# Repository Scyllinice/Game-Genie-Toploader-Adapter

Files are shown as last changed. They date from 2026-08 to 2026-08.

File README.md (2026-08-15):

# Game Genie Toploader Adapter

<p xmlns:cc="http://creativecommons.org/ns#" >This work by <span property="cc:attributionName">Scyllinice</span> is licensed under <a href="https://creativecommons.org/licenses/by-nc/4.0/?ref=chooser-v1" target="_blank" rel="license noopener noreferrer" style="display:inline-block;">Creative Commons Attribution-NonCommercial 4.0 International</a></p>



<a href="https://www.pcbway.com/project/shareproject/Game_Genie_Toploader_Adapter_25efb8dd.html">PCB from PCBWay</a>

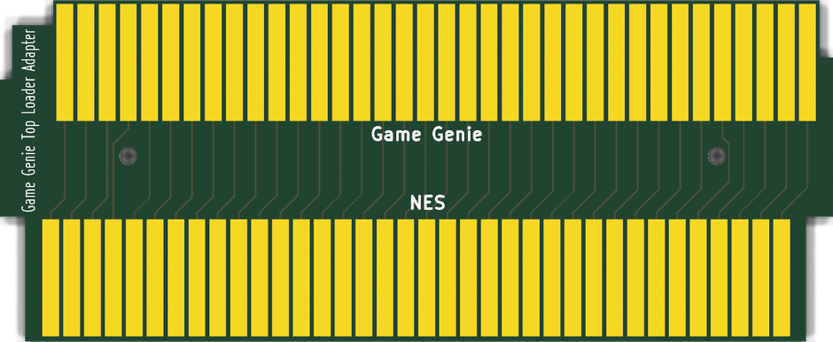
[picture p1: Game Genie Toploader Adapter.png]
Render


This is a adapter/riser PCB for using an original Game Genie on your top loading NES. It also works for clone NES systems that load directly from the cart instead of using emulation (a Retron 5, for example, will not work).

The only component needed to build this PCB into a functioning unit would be a 2.54mm pitch 2x36 pin (72 pin total) edge connector. You can search **5530843-8** for a part number as well.

I have had success using the following edge connectors:

* [Edge connector 1](https://www.aliexpress.us/item/3256802817047324.html)
* [Edge connector 2](https://www.aliexpress.us/item/2251832843397196.html)
* [DigiKey](https://www.digikey.com/en/products/detail/te-connectivity-amp-connectors/5530843-8/770547)

When soldering the edge connector to the top of the board, you will need to bend in the pins a bit as the board is only 1.2mm thick to match the original thickness of a NES retail cartridge. This helps preserve the NES cartridge connector. 

For longevity, it is recommended to use an ENIG finish with gold fingers. HASL (or Lead Free HASL) will still work, but it's more fragile and can fail over time.

[JLCPCB](https://jlcpcb.com/) is generally better priced for ENIG gold fingers than PCBWay. As the time of this writing, you can get 5 of these boards for about $20 US at JLCPCB.

## 3D printed enclosure — [`mech/`](mech/README.md)

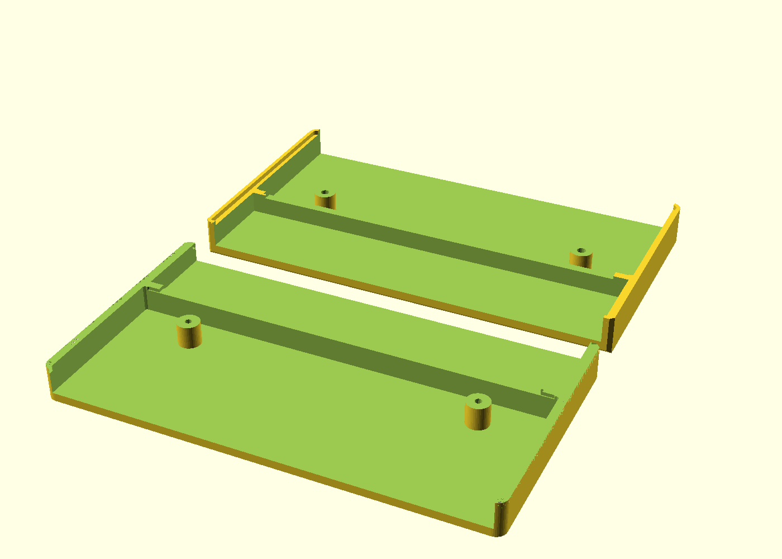
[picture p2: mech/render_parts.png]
both halves, laid out as they print


A two-part shell, **106.1 × 16.8 × 58.4 mm**, held together by two M2 screws through
the board's own mounting holes. Prints without supports; `mech/front.stl` and
`mech/back.stl` are ready to slice.

## The KiCad project lives in [`pcb/`](pcb/README.md)

The board is now **generated from source rather than drawn**: a 72-pin pinout table and
a set of measured dimensions, from which the footprints, symbols, schematic, board,
copper and fab outputs are all produced by `make rebuild`.

```
cd pcb
make            check what is committed — DRC, ERC, card-edge rules, and the
                comparison against the board that was released
make rebuild    regenerate everything from the two source tables
make fab        gerbers, drill, position file, BOM
```

Regenerating wants the pinned toolchain — `./dc bash -c "cd pcb && make rebuild"` runs
it in a container with KiCad 10 and OpenSCAD, which is what the committed files were
built with. See [`.devcontainer/`](.devcontainer/README.md). Checking works with
whatever KiCad you have.

It is the same board. The hand-drawn files this project shipped with are frozen in
[`pcb/reference/`](pcb/reference/README.md), and every run subtracts the generated
board from them — 144 pads, 72 nets, 14 outline corners, both holes, all three silk
texts, to within 1 µm. Nothing about the physical board, the pinout or the fab package
has changed.

What the rebuild adds: a schematic that passes ERC (the drawn one reports 54 direction
conflicts, because one symbol was used for both ends of a pass-through), card-edge
checks KiCad's DRC does not have (finger pitch, front/back registration, the bevel
zone, the contact wipe path), ENIG and the 1.2 mm stackup declared in the gerber job
file rather than only in this README, and a rebuild that is byte-identical run to run.

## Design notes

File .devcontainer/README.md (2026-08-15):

# Dev container — the pinned toolchain

Everything in this repository is generated, so the versions of the tools that generate
it are part of the design. This pins them.

```
./dc bash -c "cd pcb && make rebuild"     regenerate the board
./dc bash -c "cd mech && make"            regenerate the STLs
./dc                                      interactive shell
./dc --build                              rebuild the image
```

Or open the folder in VS Code and reopen in the container.

## What's inside

| tool | version | used by |
|---|---|---|
| **KiCad** (`kicad-cli` + `pcbnew` python + libraries) | 10.0.x | everything in `pcb/` |
| **OpenSCAD** (+ xvfb for PNG export) | 2021.01 | `mech/` |
| **Pillow** | distro | `pcb/gen_render.py`, which crops renders on the alpha channel |

Base is `ubuntu:24.04` with KiCad from the official PPA — `kicad-cli` and the `pcbnew`
module come from the same package, so they cannot drift apart. About 4 GB built, most
of which is `kicad-packages3d`; that is not optional, because without it every
`kicad-cli pcb render` draws a bare board and the README image comes out of that
renderer.

## Why KiCad 10 when the host has 9

**To match the desktop install.** The generators themselves do not care — the whole
`pcb/` pipeline runs unchanged on 9.0.8 and 10.0.5 and produces a board that passes
`compare_original.py` either way, verified both ways. What differs is the file they
write: 2465 lines of schema between them, none of it geometry. So regenerating on the
wrong version rewrites the committed board without changing it, and the next real
change would be invisible inside that diff.

It matters in the other direction too, and this one has actually happened: keep the
headless toolchain on 9.x, open the board once in a KiCad 10 desktop, and the desktop
upgrades the file in place — after which 9's `pcbnew` cannot load it at all
(`LoadBoard` returns `None`).

`pcb/check_toolchain.py` prints which KiCad is about to run and warns if it is not
10.x. It warns rather than fails: checking a board on whatever you have is reasonable,
and `make drc` on 9.x is perfectly valid. It is *regenerating* that costs you a diff.

## Why it is this small

A PCB toolchain will happily grow to tens of gigabytes — vendor FPGA suites, firmware
SDKs, simulators, autorouters. None of that applies to a board with no active
components on it, so none of it is here. The one omission that is a design decision
rather than a size decision is the autorouter: `pcb/route.py` solves all 72 conductors
in closed form and audits every segment before writing, and an autorouted board is a
different shape every run and cannot be reviewed as a diff.

## Not in here

Interactive GUIs: the KiCad editor and the OpenSCAD preview. Run those on the host.

## Notes

`dc` passes `--user $(id -u):$(id -g)` so files created on the bind mount stay yours,
and `PYTHONDONTWRITEBYTECODE=1` because a `.pyc` written by the container is validated
against a source mtime written by the host, and those are not the same clock. Measured
on an earlier project: an edited pin table kept importing its previous definitions from
a cached `.pyc`. Editing `pcb/lib/pinout.py`, regenerating, and getting the old nets on
a board that passes every check is the exact failure that costs a board.

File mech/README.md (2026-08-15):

# mech/ — the printed shell

A two-part enclosure for the adapter. The console end is built like a real
cartridge's — the shell carries on past the gold fingers as a skirt and the fingers
sit recessed inside a **mouth** that the console's 72-pin connector rises into. The
top is open so the Game Genie plugs straight into the edge connector.

both halves, laid out as they print

**106.1 × 16.8 × 58.4 mm** — the width and thickness are a real cartridge's. Two M2
screws. No supports, no glue, nothing else printed.

```
make            front.stl + back.stl
make gauge      the fit gauge — PRINT THIS FIRST
make render     the five PNGs in this directory
make params     re-export board.scad after a change to the PCB
```

## The console end

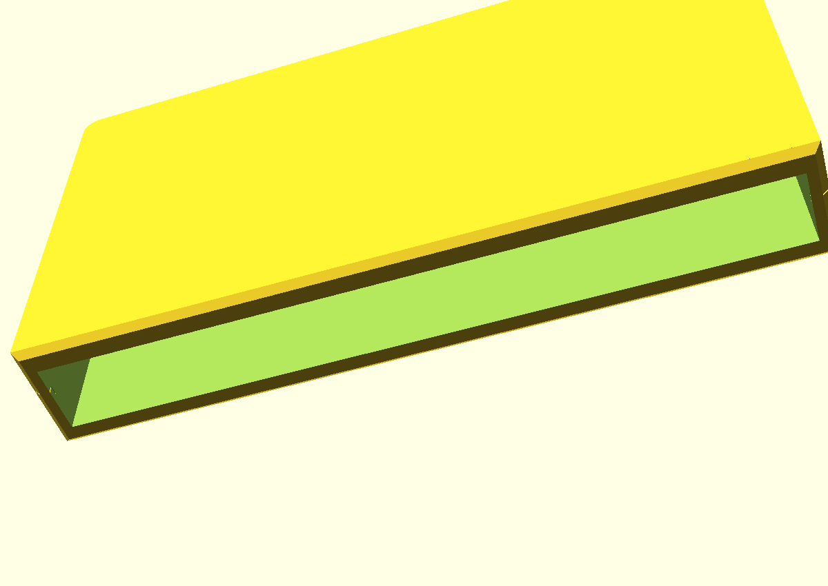
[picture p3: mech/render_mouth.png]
the mouth, from below


Those measurements were taken against a front loader, which does not weaken them
here: the top loader and the front loader take the same 72-pin connector and the same
cartridge, by design. One cart fits both, so a cart's mouth clears both connectors —
and everything in this table is a dimension *of the cartridge*, not of a console.
Console-shell features (tray posts, guide ribs, clamp pads) would not transfer, and
none of them are in this model.

| | | |
|---|---|---|
| skirt | fingers recess **7 mm** up inside the mouth | caliper on a real cart: 7.08; interference-scanning a cart through an assembled shell bounds it to 6.64–7.02 |
| mouth | **101.3 × 10.4 mm** opening | sized for the console's connector **body** (~100 × 10 mm), not for the fingers — the body is what rises into the pocket |
| lips | **3.4 mm** back face, **3.0 mm** label face | what is left of the 16.8 mm thickness either side of the mouth |
| open depth | **19.7 mm** from the bottom face | leaves **12.7 mm** of card for the connector to reach, which is exactly what a real cart leaves |
| bulkhead | closes the cavity above the mouth | the card edge seats on it; a real cart uses 1.4 mm per half, this is 2.2 mm |
| chamfer | **1 mm** at 45° round the bottom face | the lead-in; without it the shell catches on its own square edge |
| outer | **106.1 mm** wide, **16.8 mm** thick | a cart's connector-end width and its full thickness |

A guess of 1 mm for that recess failed a dry fit once, which is why it is a measured
number and not a plausible one.

## Before you print

**The board and the console end are measured. The Game Genie's edge connector is
not.** It is a bought part nobody here has calipered, and the defaults in
`enclosure.scad` are a plausible 95 × 11 × 12 mm — check yours and correct them:

| parameter | what to measure |
|---|---|
| `CONN_L` | body length, along the board |
| `CONN_D` | body depth, across the board — **this sets how thick the whole shell is** |
| `CONN_H` | body height above the board's top edge |
| `CONN_OVERLAP` | how far the body reaches down past that edge, if at all |

Then **print the fit gauge**. It is the bottom 33 mm of both halves — the mouth, the
bulkhead, the card seat, a screw pillar and the lap joint — and it answers every
tolerance question the full shell does except the Game Genie connector's. Check that
the board seats on the bulkhead without forcing, that the two halves close with no
gap, and — since printed walls come out where your printer puts them, not where the
model says — that it drops onto the console and sits down.

If the board is tight, raise `FIT` (0.25 → 0.35). If the halves rock, lower `LAP_CLR`.

## How it holds together

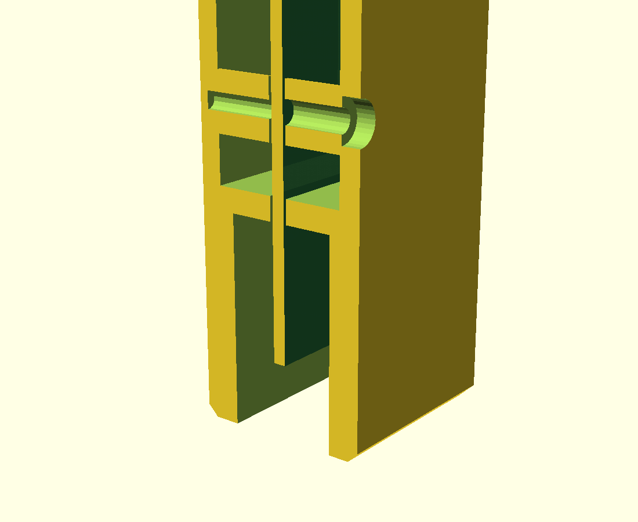
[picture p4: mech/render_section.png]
section through a screw


Three things, in order of the load they take:

**The bulkhead.** The wall that closes the mouth off from the cavity above it. The
board's shoulders — where the 93.5 mm tongue widens to the 99.7 mm body — seat on its
top face, which is also the hard stop that says how far into the console the board can
go. Pushing a Game Genie into the connector presses the board *down* onto it, so
insertion force lands on a 2.2 mm shelf instead of on the screws. A real cart does the
same job with a 1.4 mm bulkhead in each half.

**The pillars.** Two posts per half, on the board's own 2.1 mm mounting holes, which
is what those holes turn out to be good for. They set the board on the centre plane
and clamp it. They are also, deliberately, **plastic**: several traces pass within
1.5 mm of each hole, and a metal screw head torqued onto soldermask over copper can
abrade through it. The pillar is the washer. Do not counterbore the head down onto the
board.

**The screws.** 2 × M2 × 14 mm thread-forming, front to back, into a blind 1.65 mm
pilot. `enclosure.scad` prints the length it computes on every run, so it follows the
parameters if you change them.

**And a lap joint** around the wall, because the board's holes are at z=22.2 and the
shell continues for another 29 mm above them with nothing clamping it. A step around
the side walls means the top of the seam cannot open. Pegs were tried first and there
is nowhere to put them — the interior width *is* the board width plus the fit, so
anything inside the body lands on the board.

## Printing

| | |
|---|---|
| orientation | each half flat on its **outer** face — the face that ends up on the outside |
| supports | none needed; every overhang is a hole in the bed face or a wall |
| layers | 0.2 mm |
| walls | 3 perimeters (the shell is 2 mm, so this makes it solid) |
| material | PLA is fine. PETG or ABS if it will live plugged into a warm console |

The STLs in this directory are committed and are what `make` produces. They go through
`canonical_stl.py` on the way out: CGAL emits facets in an unstable order, so without
that a committed STL would be "modified" by every build and a real change would be
invisible in the diff. Same reasoning as `pcb/canonicalize.py`.

## The board dimensions are not typed in here

`board.scad` is **generated** by `gen_params.py` from `pcb/lib/geometry.py` — the same
file the PCB itself is built from. Outline, tongue, thickness, mounting holes: one
source, two consumers. Change the board and run `make params`.

It does flip the vertical axis on the way through, and that is the thing to watch if
you edit the generator: KiCad's y grows *downward* toward the insertion edge, while
the model stands the board up with z=0 at the finger tips. A model built without the
flip is upside down and looks entirely plausible, because the board is nearly
symmetrical top to bottom.

## Files

| file | |
|---|---|
| `enclosure.scad` | the model — all parameters at the top, grouped by what they affect |
| `board.scad` | GENERATED board geometry — do not edit |
| `gen_params.py` | writes `board.scad` from the PCB source |
| `canonical_stl.py` | sorts STL facets so the output is byte-reproducible |
| `front.stl`, `back.stl` | the printable halves |
| `render_*.png` | print layout, both halves, the mouth, and the section above |

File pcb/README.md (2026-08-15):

# pcb/ — the board

The Game Genie Toploader Adapter, generated from source instead of drawn. Two Python
tables describe the board — a 72-pin pinout and a set of measured dimensions — and
everything else here is produced from them: both footprints, both schematic symbols,
the schematic, the board, the copper, the project rules and the fab outputs.

**This is the project of record.** It replaced the hand-drawn files that used to sit
in the repository root, which are frozen in [`reference/`](reference/README.md) — not
as an archive, but because the check below reads them. The generated board is
subtracted from the released one on every run:

```
  PASS  outline  — 14 corners vs 14
  PASS  pad count  — 144 pads
  PASS  pad positions  — 144 pads within 0.001 mm
  PASS  pad sizes
  PASS  pad layers
  PASS  pad nets  — 72 nets
  PASS  net membership  — 72 nets
  PASS  1:1 pass-through  — 72/72 nets join J1 pin N to J2 pin N
  PASS  mounting holes  — (100.914, 79.451) d2.1, (171.348, 79.451) d2.1
  PASS  silk texts  — 3 texts

  The rebuild is geometrically and electrically identical to the released board.
```

## Running it

```
make            check what is here — DRC, ERC, card-edge rules, byte-canonical
                form, and the comparison above. Regenerates nothing.
make rebuild    the whole pipeline, pin table to routed board (FORCE=1 to overwrite
                a board that already carries routing)
make compare    just the equivalence proof
make fab        gerbers, drill, position file, BOM
make render     top and bottom PNGs, and the repository README's image
```

Needs KiCad 9 on the host — `kicad-cli` and the `pcbnew` Python module, both of which
Debian/Ubuntu's `kicad` package installs. No container. The generated files are KiCad
9 format while the released ones are KiCad 8, which is exactly why the comparison
loads both through pcbnew instead of diffing text.

## What the board is

A passive riser. 72 gold fingers go into a top-loading NES; a 2×36 2.54 mm card-edge
connector soldered to the top takes the Game Genie. Pin N to pin N, seventy-two times,
no components. The one and only complication:

**The two ends are on different pitches.** The console's cartridge slot is 2.50 mm and
the connector part is made in 2.54 mm, so every conductor has to shift sideways
between the two fields — 1.67 mm at one end of the board, 3.07 mm at the other. That
shift is the entire routing problem, and it is why the corridor between the two pad
fields is full of parallel diagonal jogs.

**Two mounting holes sit in that corridor** and four conductors cannot clear them in
either pad column, so they jog twice: once early, hold a safe X past the hole, then
finish the move in the 2.75 mm window between the hole and J1's pads. The released
board does this by hand. `route.py` derives it, and refuses to write a board where it
does not fit.

## The pipeline

```
lib/pinout.py      72 pins: nesdev name, this board's net label, symbol pin, direction
lib/geometry.py    the measured board: outline, both pad fields, holes, silk, rules
      |
      |  gen_footprints.py  -> lib/gg_adapter.pretty/   (2 footprints, 144 pads)
      |  gen_symbol.py      -> lib/gg_adapter.kicad_sym (2 symbols, mirrored)
      |  gen_schematic.py   -> gg_toploader.kicad_sch   (2 symbols, 144 labels)
      |  gen_board.py       -> gg_toploader.kicad_pcb   (placed + netted, unrouted)
      |  route.py           -> + 220 track segments, clearance-audited
      |  canonicalize.py    -> byte-reproducible (content-derived UUIDs, sorted items)
      |  gen_project.py     -> gg_toploader.kicad_pro + both lib tables
      v
   checks: kicad-cli drc (0/0) · kicad-cli erc (0) · check_fingers.py ·
           verify_rules.py · compare_original.py
```

`gen_project.py` runs **last**. `pcbnew.SaveBoard()` rewrites the sibling `.kicad_pro`
and resets the net classes to KiCad's stock defaults; `verify_rules.py` is what catches
it when that ordering slips.

## What the rebuild adds

Everything below is a difference from the released project, and each one is deliberate:

| | released | rebuild |
|---|---|---|
| ERC | 54 violations | **0** |
| symbols | one symbol used twice, all 72 nets output-to-output | two symbols, directions mirrored console↔Game Genie |
| symbol source | `doragasu:NES-CART`, a CERN-OHL-S library | generated from the nesdev wiki pin table |
| stackup finish | `None` | `ENIG` — reaches the fab in the gerber job file instead of living in a README |
| card-edge checks | none | pitch, registration, bevel zone, wipe path, mask, edge clearance |
| keepouts | none | rule areas over the bevel/wipe zone and the top edge |
| fab instructions | in this README | `fab/FABNOTES.txt`, in the zip with the gerbers |
| regeneration | n/a | byte-identical across runs |

DRC was already clean on the released board, and stays clean here: 0 violations,
0 unconnected.

## The card edge, and the check KiCad does not run

**DRC's copper-to-edge test does not look at pads.** Measured here: set
`min_copper_edge_clearance` to 5 mm — far enough that all 144 pads are inside it — and
the violation list comes back with 16 items, every one a *track*. Not one pad, at any
setting. On most boards that is a curiosity. On a card edge the pads are the thing
nearest the milled edge, so the check that matters is the one that does not run.

Two things cover it between them:

**Rule areas** (`gen_board.py`) over the bevel/wipe zone at the insertion edge and over
the top edge. Nothing may be *routed* into either band. The insertion-edge one is there
twice over: a 45° gold-finger bevel takes ~0.6 mm off the top surface, so copper inside
it is copper the mill cuts through — and the console's contacts sweep that same strip
on every insertion, so a track crossing it shorts to each contact as it passes. They
are rule areas, not copper: the gerbers are byte-identical with and without them,
verified.

**`check_fingers.py`** measures what a keepout cannot enforce, because keepouts permit
pads. It reports the closest pad to any edge — J1.36 at **0.372 mm** — and fails only
below 0.20 mm, the floor a fab can actually hold on a routed edge. All 72 J1 pads sit
inside this project's own 0.5 mm rule, at 0.468 mm from the top edge. That is
as-released and as-fabricated: the connector land has to be where the connector is.
Noted every run, not changed.

**The bevel itself is not board geometry** — it is a process the fab applies, and
there is no field in any gerber that asks for it. That instruction now ships as
`fab/FABNOTES.txt` inside the fab package rather than living in a README, because a
fab that is not told sends back square-edged contacts that chew the console connector.

## Things worth knowing about this board

* **1.2 mm, not 1.6 mm.** Cartridge thickness. The stackup declares 1.11 mm core plus
  copper and mask to reach it, and the gerber job carries the number.
* **The finger setback is 0.62 mm** and a 45° gold-finger bevel on a 1.2 mm board
  reaches about 0.6 mm. That is a **0.02 mm margin** — `check_fingers.py` prints it
  every run because it is the kind of number you want to have seen before ordering.
* **Pins 1 and 72 are both GND and are NOT joined here.** They are separate nets
  (`CPU-GND`, `CIC-GND`) and meet in the console. `pinout.py` asserts it stays that
  way; bridging them would be a change of circuit, not a cleanup.
* **PPU A11 and A10 really are swapped** at pins 62/63. Wiki and released board agree.
* **CIRAM A10 and CIRAM /CE are driven by the cartridge**, so they are the two signals
  whose direction runs Game-Genie-to-console. The released symbol has them as inputs;
  this is the only place the rebuild's pin table disagrees with it, and it changes
  nothing but ERC.

## Traps this cost, written down where they happened

* `.kicad_pcb` writes text size in the **opposite order** to `VECTOR2I`, and
  `SetBold()` **recomputes thickness**, so it has to be called before setting it.
  Between them, the long silk text came out short, fat and off the edge.
* A schematic's inlined `lib_symbols` copy is **library-qualified**, but its
  `_0_0`/`_1_1` sub-symbols are **not**. Get it wrong and KiCad rejects the whole file
  with "Failed to load schematic" and no line number.
* That inlined copy is compared **field by field** against the library. A description
  that differs by one word is an ERC warning, which is why both files build their
  symbols from one table.
* The escape columns beside a mounting hole are `hx ± R`, and `(hx - R) - hx` is not
  exactly `-R` in floating point, so an exact-fit candidate rejects itself. Two
  conductors failed to route over 1e-13 mm.

## Files

| file | what it makes |
|---|---|
| `lib/pinout.py` | the 72-pin table — run it to print the pinout |
| `lib/geometry.py` | measured geometry — run it to print the dimensions |
| `gen_footprints.py` | `lib/gg_adapter.pretty/` — the fingers and the connector land |
| `gen_symbol.py` | `lib/gg_adapter.kicad_sym` — two direction-mirrored symbols |
| `gen_schematic.py` | the schematic: two symbols, 144 labels, no wires |
| `gen_board.py` | the board: outline, placement, holes, silk, 72 nets |
| `route.py` | the copper, in closed form, clearance-audited before it is written |
| `canonicalize.py` | content-derived UUIDs so a no-op rebuild is a no-op diff |
| `gen_project.py` | net classes, design rules, both library tables |
| `gen_bom.py` | the BOM — one line, plus the fab notes that matter |
| `gen_render.py` | the two renders, and the repository README's image |
| `compare_original.py` | the equivalence proof against the released board |
| `check_fingers.py` | card-edge checks KiCad's DRC does not have |
| `verify_rules.py` | asserts `SaveBoard()` has not eaten the net classes |
| `guard_routed.py` | refuses to regenerate over routing |
| `reference/` | the released design, frozen — what `compare_original.py` reads |

## Changing the board

Edit the table, not the file. A pin's net name lives in `lib/pinout.py`; a dimension
lives in `lib/geometry.py`; where the copper goes is a rule in `route.py`. Then
`make rebuild`, and read the diff — it will be small, because the board is
canonicalised.

Opening `gg_toploader.kicad_pcb` in KiCad and dragging something works, and the next
`make rebuild` discards it. That is not a warning against using the GUI: it is the
fastest way to try a change. Try it there, then fold the numbers back into the table
that owns them.

One consequence of the promotion is worth stating plainly: **`make compare` is now a
regression test, not a migration check.** It answers "does the board still match what
was fabricated and sold", so a deliberate design change is supposed to break it. When
that happens, the fix is to read exactly which of the fourteen lines changed, satisfy
yourself that it is the change you meant, and say so in the commit — not to relax the
check. `reference/` never moves.

`production/` in the repository root is the fab package the released board was ordered
from. It has not been regenerated: it corresponds to the design this board is proven
identical to, and `make fab` produces its replacement when there is a reason to order
again.

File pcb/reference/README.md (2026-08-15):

# reference/ — the released design, frozen

These are the hand-drawn KiCad files this project shipped with: the board that was
fabricated, sold, listed on PCBWay and plugged into people's consoles. They lived in
the repository root until the generated project in `../` took over as the project of
record.

**Nothing builds from this directory and nothing regenerates it.** It is here for one
reason: `../compare_original.py` loads `Game Genie Toploader Adapter.kicad_pcb` on
every run and subtracts it from the generated board — 14 outline corners, 144 pads,
72 net groups, 2 holes, 3 silk texts, all to 1 µm. Delete this and that proof becomes
an assertion.

Kept complete rather than just the one file the check reads, so the released design
can still be opened and looked at:

| | |
|---|---|
| `Game Genie Toploader Adapter.kicad_pcb` | the released board — **what the comparison reads** |
| `Game Genie Toploader Adapter.kicad_sch` | the released schematic (ERC: 54 direction conflicts, see `../README.md`) |
| `Game Genie Toploader Adapter.kicad_pro` | its project settings |
| `nes-cart.kicad_sym` | its symbol library |
| `NES.pretty/`, `Game Genie.pretty/` | its two hand-drawn footprints |
| `fp-lib-table`, `sym-lib-table` | library tables, `${KIPRJMOD}`-relative, so they still resolve here |
| `fabrication-toolkit-options.json` | config for the Fabrication Toolkit plugin it was ordered with |

If you edit anything in here, the comparison stops meaning what it says.

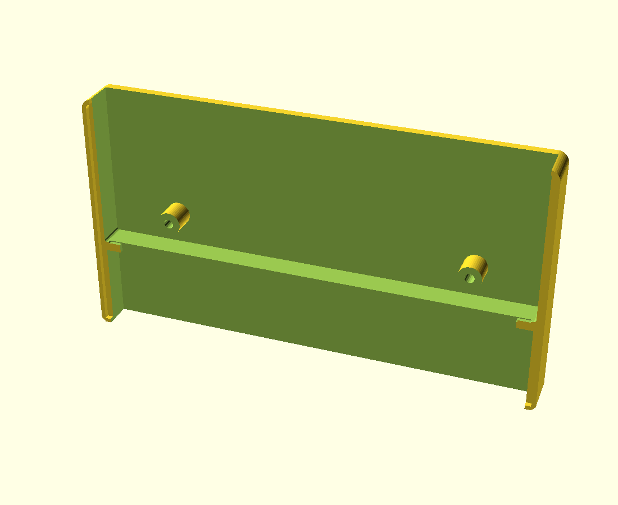
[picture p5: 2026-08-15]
mech/render_front.png

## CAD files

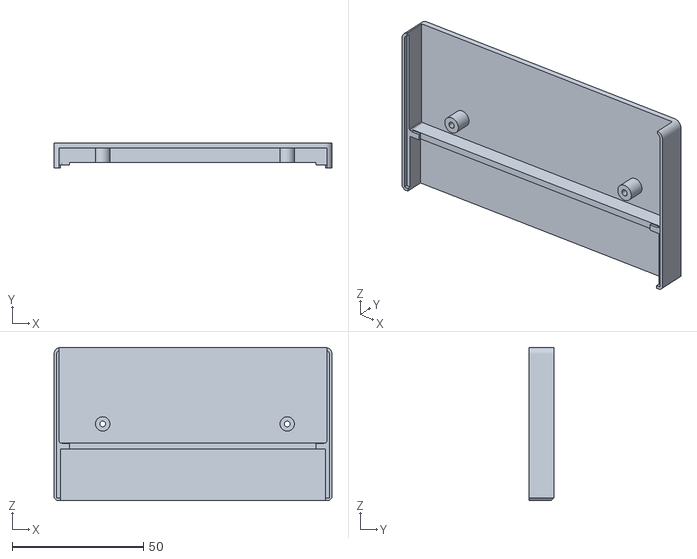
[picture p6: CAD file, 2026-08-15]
mech/front.stl
106.1 x 9.60 x 58.4

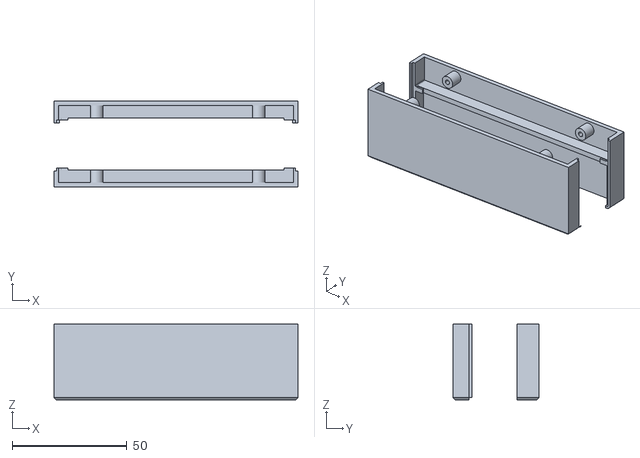
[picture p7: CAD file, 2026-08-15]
mech/gauge.stl
106.1 x 37.6 x 33.0

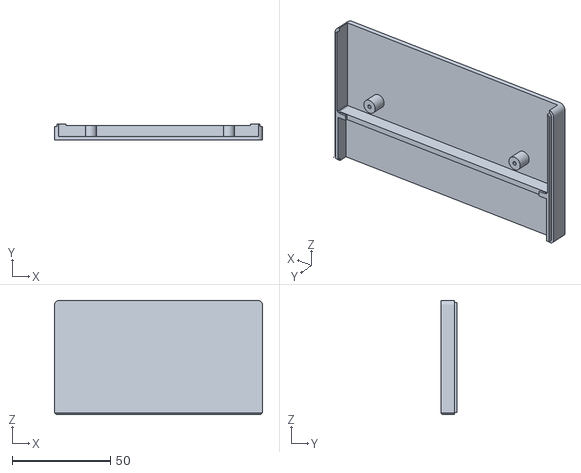
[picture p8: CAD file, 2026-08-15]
mech/back.stl
106.1 x 8.40 x 58.4

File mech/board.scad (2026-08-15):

// GENERATED by mech/gen_params.py from pcb/lib/geometry.py — do not edit.
//
// x: across the board, 0 = board centre
// z: up from the finger tips, 0 = insertion edge

BOARD_T          = 1.2;   // 1.2 mm — cartridge thickness
BOARD_W          = 99.7204;
BOARD_H          = 40.894;

TONGUE_ROOT_Z    = 14.9352;   // shoulders — shell stops here
TONGUE_W         = 93.472;
TONGUE_LEFT_X    = -46.8122;
TONGUE_RIGHT_X   = 46.6598;
TOP_EDGE_Z       = 40.894;   // where the edge connector is fitted

// The two 2.1 mm holes, which are what the enclosure screws through.
MOUNT_D          = 2.1;
MOUNT_POS = [
    [-34.4678, 22.225],   // MOUNT1
    [35.9664, 22.225],   // MOUNT2
];

// The connector pad field: the top edge is where the edge connector clamps on,
// and its bent tails lie along these pads on both faces.
PAD_FIELD_Z0     = 26.4264;   // lower end of the pads
PAD_FIELD_Z1     = 40.4264;   // upper end, 0.4676 mm below the edge
PAD_FIELD_W      = 90.9;

// Board outline, x/z, in KiCad's winding order.
BOARD_OUTLINE = [
    [-46.8122, 0.0],
    [46.6598, 0.0],
    [46.6598, 14.9352],
    [49.8602, 14.9352],
    [49.8602, 34.036],
    [48.26, 34.036],
    [48.26, 40.894],
    [-43.4594, 40.894],
    [-43.4594, 37.9222],
    [-48.3616, 37.9222],
    [-48.3616, 31.3944],
    [-49.8602, 31.3944],
    [-49.8602, 14.9352],
    [-46.8122, 14.9352],
];

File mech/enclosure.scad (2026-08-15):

// Game Genie Toploader Adapter — two-part printed shell.
//
//   make            front.stl + back.stl
//   make render     PNGs of both halves and the assembly
//   openscad enclosure.scad            preview (part = "assembly")
//
// The board stands up in use: gold fingers down into the console, the 2x36 edge
// connector on top with the Game Genie plugged into it.
//
// THE CONSOLE END IS BUILT LIKE A CARTRIDGE'S, from measured cart geometry (see the
// block below). The shell does not stop at the fingers and let them hang out in the
// air — it carries on past them as a skirt, and the fingers sit recessed 7 mm up
// inside a MOUTH that the console's 72-pin connector body rises into. Outer size is
// the cart's too: 106.1 mm across the connector end, 16.8 mm thick.
//
// WHAT HOLDS THE BOARD, in order of how much load each part takes:
//
//   the BULKHEAD   The wall that closes the mouth off from the cavity above it. The
//                  board's shoulders — where the 93.5 mm tongue widens to the 99.7 mm
//                  body — seat on its top face, which is also what stops the board
//                  being pushed further into the console. Pushing a Game Genie in
//                  presses the board DOWN onto it, so insertion force goes into a
//                  2.2 mm plastic shelf and not into the screws. A real cart does the
//                  same thing with a 1.4 mm bulkhead per half.
//   the PILLARS    Two internal posts per half, on the board's own 2.1 mm mounting
//                  holes. They set the board on the centre plane and clamp it.
//   the SCREWS     Two M2, front to back, through those same holes. They hold the
//                  halves together; they are not carrying the board.
//
// The pillar faces are plastic bearing on soldermask over copper — several traces
// pass within 1.5 mm of each hole (route.py steers them around it). Plastic is the
// right material for that: a bare metal screw head torqued onto soldermask over a
// trace can abrade through it over time, which is the reason fibre washers get
// specified under screw heads on boards like this. Here the pillar IS the washer.
// Do not counterbore the head down onto the board.
//
// DIMENSIONS YOU MUST CHECK BEFORE PRINTING are collected under "edge connector"
// below. Everything about the BOARD is generated from the PCB source
// (board.scad <- mech/gen_params.py <- pcb/lib/geometry.py) and needs no checking;
// the connector is a bought part nobody here has measured. Print the fit gauge
// (part = "gauge") first — it is 8 grams and it answers the same questions the full
// shell does, an hour sooner.

include <board.scad>

/* [What to build] */
// front = the half you see, back = the half with the screw threads
part = "assembly";  // [front, back, parts, assembly, section, gauge]

/* [Fit] */
// Clearance around the board inside its slot, per side. 0.25 suits a well-tuned
// FDM printer at 0.2 mm layers; go to 0.35 if your first layer squishes wide.
FIT = 0.25;
// Wall thickness. 2.0 is four perimeters at 0.5 mm and is stiff enough at this size.
WALL = 2.0;
// Outer corner rounding.
CORNER_R = 2.5;

/* [Edge connector — MEASURE YOUR PART] */
// A TE 5530843-8 (or the AliExpress equivalents the README lists). These are the
// numbers to caliper: the shell's whole upper half is built from them, and they are
// the only figures in this model that were not taken from the board.
//
// CONN_L/CONN_D are the BODY, not the pin span. CONN_H is measured from where the
// body sits on the board's top edge to the top of the plastic.
CONN_L = 95.0;    // along the board
CONN_D = 11.0;    // across the board — this sets how thick the whole shell is
CONN_H = 12.0;    // above the board's top edge
// How far the connector body reaches DOWN past the board's top edge, if it does.
CONN_OVERLAP = 0.0;
// Gap between the connector and the shell around it.
CONN_CLR = 0.6;
// The shell stops this far below the top of the connector, so the shell can never
// be what a Game Genie lands on — it has to seat on the connector itself.
HOOD_DROP = 1.5;

/* [Fasteners] */
SCREW_CLR_D = 2.2;   // through the front half
SCREW_HEAD_D = 4.0;  // counterbore in the front face
SCREW_HEAD_H = 1.8;
PILOT_D = 1.65;      // back half: thread-forming M2 bites into this
PILLAR_D = 5.5;
PILOT_SKIN = 0.8;    // plastic left at the bottom of the blind pilot hole

/* [Assembly aids] */
// A LAP JOINT AROUND THE WALL, not locating pegs.
//
// Pegs were the first attempt and there is nowhere to put them: the interior width
// IS the board width plus the fit, by construction, so the board fills the shell
// wall to wall and any peg inside the body lands on it. There is a little room in
// the floor beside the tongue and a little beside the connector, but both are ~2 mm
// and a 2 mm printed peg in a 2 mm pocket is a coin toss.
//
// The lap is better anyway, because the problem is not really alignment — the board
// itself aligns the halves, sitting in a slot in both. The problem is that the only
// screws are at z=22.2 (the board's holes are where they are) and the shell carries
// on for another 29 mm above them with nothing holding the two sides together. A
// step around the wall means the top of the seam cannot open even though nothing
// clamps it there.
LAP_W = WALL / 2;    // how much of the wall thickness the step takes
LAP_H = 1.2;         // how far it crosses the parting plane
LAP_CLR = 0.15;      // groove is this much looser than the tongue

/* [The console end — MEASURED FROM A REAL NES CARTRIDGE] */
// These are not guesses. Every number in this block is mesh-measured off a real NES
// cartridge and dry-fit verified in a console; they are the reason this end is
// cartridge-shaped rather than a flat slab with the fingers hanging out of it.
//
// AND YES, THEY APPLY TO A TOP LOADER. The obvious objection to cart geometry in a
// NES-101 adapter is that it might have been taken against a front loader — it was.
// It does not matter: the two consoles take the same 72-pin connector and the same
// cartridge, by design. One cart fits both, so the cart's own mouth clears both
// connectors, and every dimension here is a dimension OF THE CARTRIDGE rather than
// of either console.
//
// What does NOT transfer is anything describing contact with a console's SHELL —
// front-loader tray posts, guide ribs, clamp pads, the thumb-pocket dish a tray post
// lands in. None of that is in this model; there is nothing here but the mouth.
//
// A real cart does NOT expose its fingers. The shell continues past them as a skirt,
// the fingers sit recessed up inside a MOUTH, and the console's 72-pin connector body
// rises into that mouth as the cart seats. Plastic below, above and beside the card
// edge — which is why you can drop a cartridge on the floor and still play it.
//
// The chain that has to hold, or the board never seats:
//   the mouth must clear the CONNECTOR BODY (~100 x 10 mm), not just the fingers
//   the mouth must stay open far enough up for the connector to reach the fingers
//   the bulkhead behind it is the hard stop, and the card edge seats against it
CART_T       = 16.8;   // real cart assembled thickness — this sets the shell's depth
CART_NOSE_W  = 106.1;  // real cart width AT THE CONNECTOR END (the body is 119.3 and
                       //   steps in to this over the bottom 24.3 mm; we are already
                       //   narrower than the body, so we are all nose)
EDGE_RECESS  = 7.0;    // how far the fingers recess UP inside the mouth. Caliper on a
                       //   real cart: 7.08. Interference-scanning a cart through an
                       //   assembled shell bounds it to 6.64..7.02. A guess of 1 mm
                       //   failed the dry fit, which is how it came to be measured.
MOUTH_W      = 101.3;  // mouth width — ~0.65 mm/side over a 100 mm connector body
MOUTH_H      = 10.4;   // mouth opening in the thickness direction
MOUTH_LIP_BOT = 3.4;   // material below the mouth on the back face (top lip = 3.0)
MOUTH_OPEN   = 19.7;   // mouth stays open this far up from the bottom face; above it
                       //   the bulkhead closes the cavity down to the board slot
EDGE_CHAMF   = 1.0;    // 45-degree lead-in chamfer around the bottom face

$fa = 2;
$fs = 0.4;

// ---------------------------------------------------------------------------
// Derived
// ---------------------------------------------------------------------------
SLOT_T   = BOARD_T + 2 * FIT;                     // board slot thickness
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

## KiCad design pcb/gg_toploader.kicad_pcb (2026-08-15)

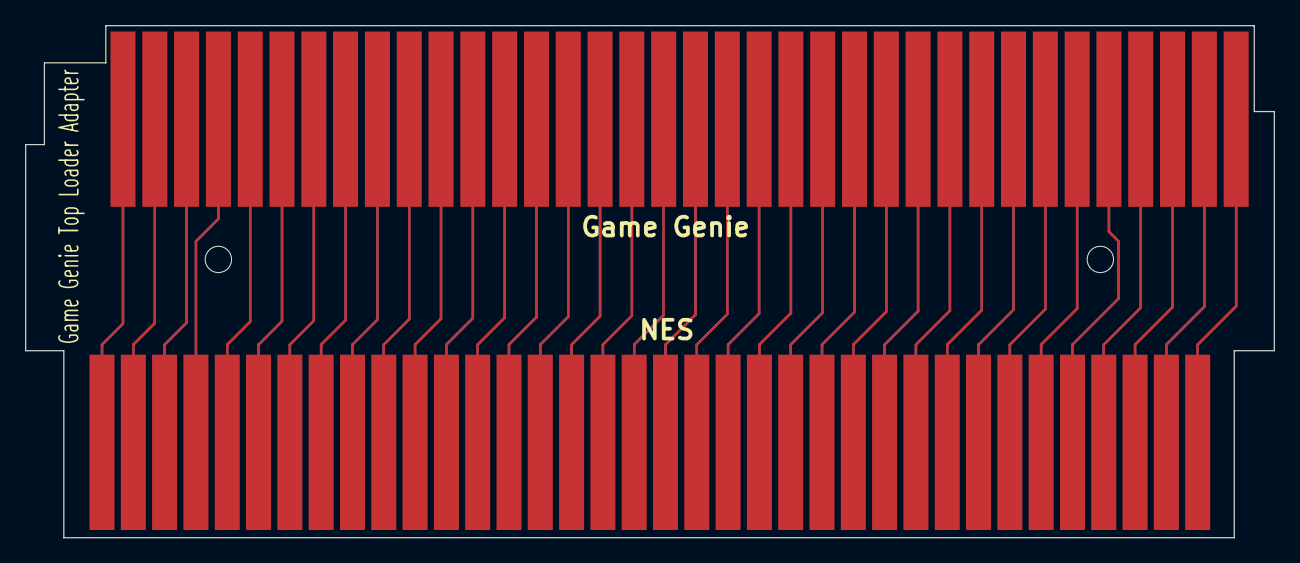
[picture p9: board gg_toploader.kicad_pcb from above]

Board: 2 copper layers, 99.7 x 40.9 mm, 4 parts (0 on the bottom side), 72 nets.

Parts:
J1: 5530843-8; GG_2x36_2.54mm_Edge
J2: NES_CART_FINGERS
MOUNT1, MOUNT2: MountingHole_2.1mm

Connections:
/4MHz: J1.71, J2.71
/21.48MHz: J1.37, J2.37
/CIC-GND: J1.72, J2.72
/CIC-VCC: J1.36, J2.36
/CPU-A0: J1.13, J2.13
/CPU-A1: J1.12, J2.12
/CPU-A2: J1.11, J2.11
/CPU-A3: J1.10, J2.10
/CPU-A4: J1.9, J2.9
/CPU-A5: J1.8, J2.8
/CPU-A6: J1.7, J2.7
/CPU-A7: J1.6, J2.6
/CPU-A8: J1.5, J2.5
/CPU-A9: J1.4, J2.4
/CPU-A10: J1.3, J2.3
/CPU-A11: J1.2, J2.2
/CPU-A12: J1.39, J2.39
/CPU-A13: J1.40, J2.40
/CPU-A14: J1.41, J2.41
/CPU-D0: J1.49, J2.49
/CPU-D1: J1.48, J2.48
/CPU-D2: J1.47, J2.47
/CPU-D3: J1.46, J2.46
/CPU-D4: J1.45, J2.45
/CPU-D5: J1.44, J2.44
/CPU-D6: J1.43, J2.43
/CPU-D7: J1.42, J2.42
/CPU-GND: J1.1, J2.1
/CPU-R/~W: J1.14, J2.14
/CPU-~IRQ: J1.15, J2.15
/CPU-~PRG: J1.50, J2.50
/EXP0: J1.16, J2.16
/EXP1: J1.17, J2.17
/EXP2: J1.18, J2.18
/EXP3: J1.19, J2.19
/EXP4: J1.20, J2.20
/EXP5: J1.55, J2.55
/EXP6: J1.54, J2.54
/EXP7: J1.53, J2.53
/EXP8: J1.52, J2.52
/EXP9: J1.51, J2.51
/PHI2: J1.38, J2.38
/PPU-A0: J1.29, J2.29
/PPU-A1: J1.28, J2.28
/PPU-A2: J1.27, J2.27
/PPU-A3: J1.26, J2.26
/PPU-A4: J1.25, J2.25
/PPU-A5: J1.24, J2.24
/PPU-A6: J1.23, J2.23
/PPU-A7: J1.59, J2.59
/PPU-A8: J1.60, J2.60
/PPU-A9: J1.61, J2.61
/PPU-A10: J1.63, J2.63
/PPU-A11: J1.62, J2.62
/PPU-A12: J1.64, J2.64
/PPU-A13: J1.65, J2.65
/PPU-D0: J1.30, J2.30
/PPU-D1: J1.31, J2.31
/PPU-D2: J1.32, J2.32
/PPU-D3: J1.33, J2.33
/PPU-D4: J1.69, J2.69
/PPU-D5: J1.68, J2.68
/PPU-D6: J1.67, J2.67
/PPU-D7: J1.66, J2.66
/PPU-VA10: J1.22, J2.22
/PPU-~A13: J1.58, J2.58
/PPU-~R: J1.21, J2.21
/PPU-~VCS: J1.57, J2.57
/PPU-~W: J1.56, J2.56
/S0: J1.34, J2.34
/S1: J1.35, J2.35
/S2: J1.70, J2.70

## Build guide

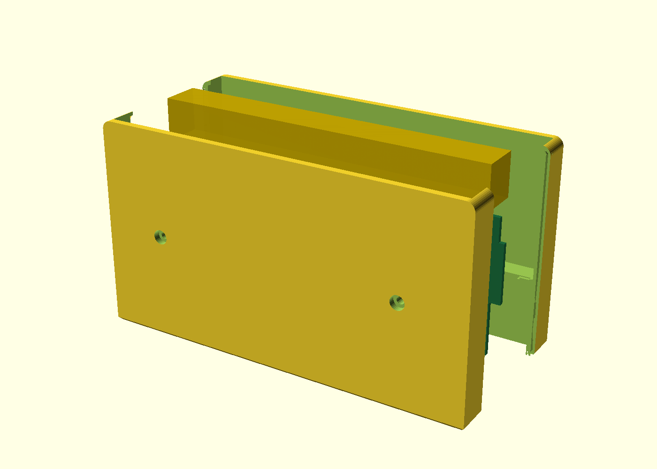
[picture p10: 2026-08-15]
mech/render_assembly.png

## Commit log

2026-08-15 Commit KiCAD files
    [Game Genie Toploader Adapter.kicad_pcb, Game Genie Toploader Adapter.kicad_sch, designators.csv]
2026-08-15 Add note about JLCPCB
    Make the board scriptable
    Add back renders
    [Game Genie Toploader Adapter.kicad_pcb, Game Genie Toploader Adapter.kicad_sch, back.stl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]
